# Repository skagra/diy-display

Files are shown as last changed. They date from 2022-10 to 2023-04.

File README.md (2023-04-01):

# DIY DISPLAY

A simple memory mapped *OLED display* for the [DIY CPU](https://github.com/skagra/diy-cpu-meta) project.

A `SSD1306` OLED is used to show:

* Two digital values (`value 1` and `value 2`), in binary, hex and decimal.
* A scrolling line of text.

# Interface

The display is interrupt driven.  If the `ENABLE` pin is high, then on a rising edge on the `INTERRUPT` pin the following values are captured :

* `DATA` - 8 bits of data.
* `ADDR` - 2 bits indicating whether the data value should be shown as `value 1`, `value 2` or on the scrolling text line.

`ADDR` encoding is:

| Value | Meaning |
| ----- | --- |
| 0x00  | Digital value 1 |
| 0x01  | Digital value 2 |
| 0x02  | Scrolling text  |
| 0x11  | Unused |

# Circuit

The pin out is defined in [Pins.h](Pins.h).

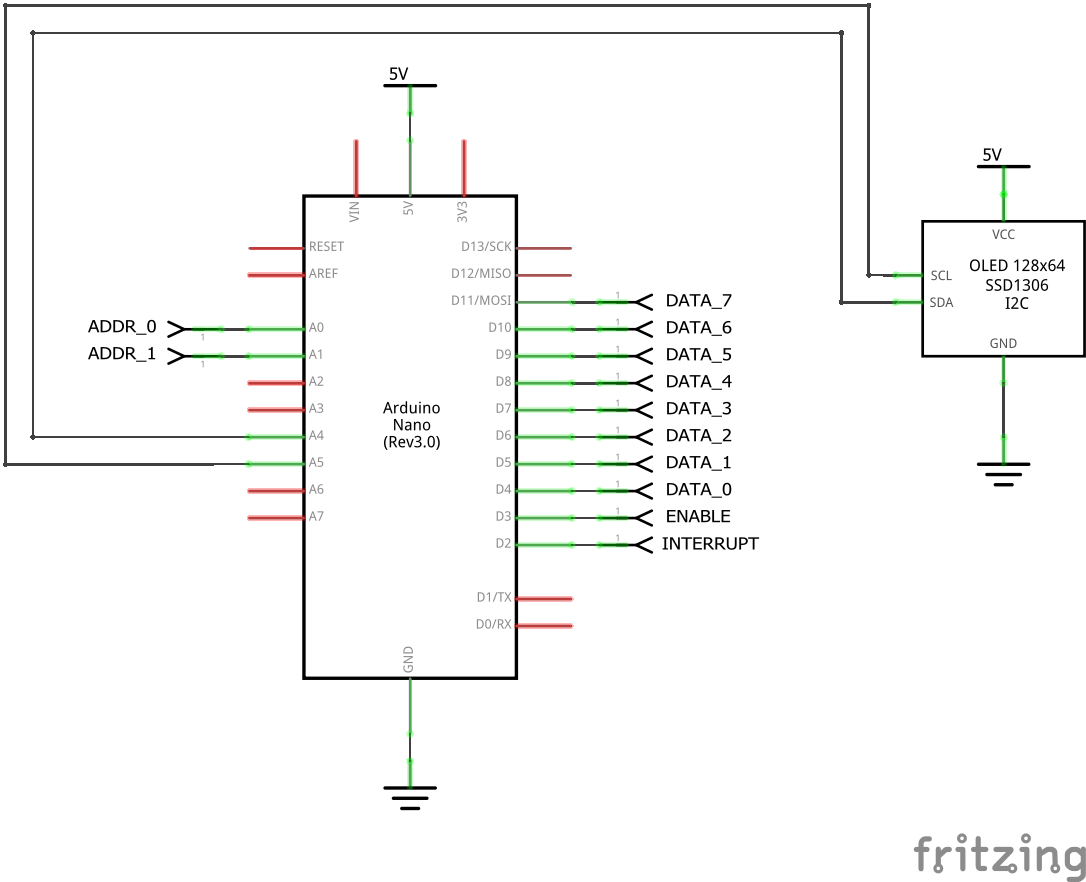
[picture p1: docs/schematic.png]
Schematic


# Testing

A separate testing project, which puts the display through its paces, may be found [here](https://github.com/skagra/diy-display-tester).

# Board

The following shows the display board together with the test rig.

Board

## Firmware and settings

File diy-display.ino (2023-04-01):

#include "Pins.h"
#include <Adafruit_SSD1306.h>
#include <splash.h>

#include <Wire.h>
#include <Adafruit_GFX.h>
#include "StatusDisplay.h"

/*
 * Operation values encoded on the address lines.
 *
 * Each value defines a particular display location/format.
 */
#define OP_VALUE_ONE 0x00 // Display on digital value 1
#define OP_VALUE_TWO 0x01 // Display on digital value 2
#define OP_MESSAGE 0x02   // Display on scrolling text line

/*
 * SSD1306 OLED Display settings
 *
 * Note: This display uses i2c and so the SDA and SCL (A4/A5 on a Nano)
 */
#define SCREEN_ADDRESS 0x3C
#define SCREEN_WIDTH 128 // OLED display width, in pixels
#define SCREEN_HEIGHT 64 // OLED display height, in pixels
#define OLED_RESET -1    // Reset pin # (or -1 if sharing Arduino reset pin)

// SSD1306 OLED display
Adafruit_SSD1306 display(SCREEN_WIDTH, SCREEN_HEIGHT, &Wire, OLED_RESET);

// Display code
StatusDisplay *statusDisplay;

void setup()
{
    Serial.begin(9600);

    pinMode(PIN_ADDR_A0, INPUT);
    pinMode(PIN_ADDR_A1, INPUT);

    pinMode(PIN_DATA_0, INPUT);
    pinMode(PIN_DATA_1, INPUT);
    pinMode(PIN_DATA_2, INPUT);
    pinMode(PIN_DATA_3, INPUT);
    pinMode(PIN_DATA_4, INPUT);
    pinMode(PIN_DATA_5, INPUT);
    pinMode(PIN_DATA_6, INPUT);
    pinMode(PIN_DATA_7, INPUT);

    pinMode(PIN_ENABLE, INPUT);
    pinMode(PIN_INTERRUPT, INPUT);

    // SSD1306_SWITCHCAPVCC = generate display voltage from 3.3V internally
    if (!display.begin(SSD1306_SWITCHCAPVCC, SCREEN_ADDRESS))
    {
        Serial.println(F("SSD1306 allocation failed"));
        for (;;)
            ;
    }

    statusDisplay = new StatusDisplay(&display);

    statusDisplay->setHexValueOne(0xFF);
    statusDisplay->setHexValueTwo(0xFF);
    statusDisplay->addMessage("DIY CPU");
    statusDisplay->display();
    delay(500);
    statusDisplay->addMessage("...READY!");
    statusDisplay->display();
    delay(500);
    statusDisplay->clearMessage();
    statusDisplay->setHexValueOne(0);
    statusDisplay->setHexValueTwo(0);
    statusDisplay->display();

    attachInterrupt(digitalPinToInterrupt(PIN_INTERRUPT), handleInterrupt, RISING);
}

// Globals to grab data/addr values
#define BUFFER_SIZE 64

byte addrBuffer[BUFFER_SIZE];
byte dataBuffer[BUFFER_SIZE];
volatile int writeBufferIndex = 0;
volatile int buffered = 0;
volatile int readBufferIndex = 0;

void handleInterrupt()
{
    if (digitalRead(PIN_ENABLE) == HIGH && buffered < BUFFER_SIZE)
    {
        // Get the address bits
        addrBuffer[writeBufferIndex] = PINC & 0x03;

        // Get the data bits
        dataBuffer[writeBufferIndex] = (PIND >> 4) | (PINB << 4);

        if (writeBufferIndex < BUFFER_SIZE - 1)
        {
            writeBufferIndex++;
        }
        else
        {
            writeBufferIndex = 0;
        }
        buffered++;
    }
}

// Character buffer to send message characters to display
char messageBuffer[2];

void loop()
{
    if (buffered > 0)
    {
        noInterrupts();
        byte localAddr = addrBuffer[readBufferIndex];
        byte localData = dataBuffer[readBufferIndex];

        if (readBufferIndex < BUFFER_SIZE - 1)
        {
            readBufferIndex++;
        }
        else
        {
            readBufferIndex = 0;
        }
        buffered--;
        interrupts();

        switch (localAddr)
        {
        case (OP_VALUE_ONE):
            statusDisplay->setHexValueOne(localData);
            break;
        case (OP_VALUE_TWO):
            statusDisplay->setHexValueTwo(localData);
            break;
        case (OP_MESSAGE):
            if (localData != 0)
            {
                messageBuffer[0] = localData;
                messageBuffer[1] = (char)0;
                statusDisplay->addMessage(messageBuffer);
            }
            else
            {
                statusDisplay->clearMessage();
            }
            break;
        default:
            Serial.println("ERROR: Invalid address");
            break;
        }
        statusDisplay->display();
    }
}

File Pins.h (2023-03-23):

#ifndef _PIN_DOT_H_
#define _PIN_DOT_H_

/*
 * DATA
 *
 * Byte to display:
 *
 * - LSB is on lowest numbered pin
 * - The byte is interpreted either as a character or a number
 *   depending on the operation selected by the ADDR pins.
 */
#define PIN_DATA_0 4  // PIN 7
#define PIN_DATA_1 5  // PIN 8
#define PIN_DATA_2 6  // PIN 9
#define PIN_DATA_3 7  // PIN 10
#define PIN_DATA_4 8  // PIN 11
#define PIN_DATA_5 9  // PIN 12
#define PIN_DATA_6 10 // PIN 13
#define PIN_DATA_7 11 // PIN 14

/*
 * ADDR
 *
 * The value selects the operation (below).
 *
 * - LSB is on lowest numbered pin
 */
#define PIN_ADDR_A0 PIN_A0 // PIN 10
#define PIN_ADDR_A1 PIN_A1 // PIN 20

/*
 * Interrupt
 *
 * Values are read from the DATA and ADDR pins on a rising edge on the interrupt line.
 */
#define PIN_INTERRUPT 2 // PIN 5

/*
 * ENABLE
 *
 * Values will only be read from DATA and ADDR when ENABLE is high.
 */
#define PIN_ENABLE 3 // PIN 6

#endif

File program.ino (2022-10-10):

#include <Adafruit_SSD1306.h>
#include <splash.h>

#include <Adafruit_SSD1306.h>
#include <Wire.h>
#include <Adafruit_GFX.h>
#include "StatusDisplay.h"

#define PIN_DATA_0 4  // PIN 7
#define PIN_DATA_1 5  // PIN 8
#define PIN_DATA_2 6  // PIN 9
#define PIN_DATA_3 7  // PIN 10
#define PIN_DATA_4 8  // PIN 11
#define PIN_DATA_5 9  // PIN 12
#define PIN_DATA_6 10 // PIN 13
#define PIN_DATA_7 11 // PIN 14

#define PIN_ADDR_A0 PIN_A0 // PIN 10
#define PIN_ADDR_A1 PIN_A1 // PIN 20
#define PIN_ADDR_A2 PIN_A2 // PIN 21
#define PIN_ADDR_A3 PIN_A3 // PIN 22

#define PIN_ENABLE 3 // PIN 6
#define PIN_CLOCK 2  // PIN 5

#define SCREEN_ADDRESS 0x3C
#define SCREEN_WIDTH 128 // OLED display width, in pixels
#define SCREEN_HEIGHT 64 // OLED display height, in pixels
#define OLED_RESET -1    // Reset pin # (or -1 if sharing Arduino reset pin)

// SDA 23 A4
// SCL 24 A5

#define OP_VALUE_ONE 0x00
#define OP_VALUE_TWO 0x01
#define OP_MESSAGE 0x02

Adafruit_SSD1306 display(SCREEN_WIDTH, SCREEN_HEIGHT, &Wire, OLED_RESET);
StatusDisplay *statusDisplay;

void setup()
{
    Serial.begin(9600);

    // SSD1306_SWITCHCAPVCC = generate display voltage from 3.3V internally
    if (!display.begin(SSD1306_SWITCHCAPVCC, SCREEN_ADDRESS))
    {
        Serial.println(F("SSD1306 allocation failed"));
        for (;;)
            ;
    }

    statusDisplay = new StatusDisplay(&display);

    attachInterrupt(digitalPinToInterrupt(PIN_CLOCK), handleClock, RISING);
}

volatile byte addr;
volatile byte data;
volatile bool dataExists = false;

void handleClock()
{
    if (digitalRead(PIN_ENABLE) == HIGH)
    {
        // Get the address bits
        addr = (digitalRead(PIN_ADDR_A0) == HIGH) |
               (digitalRead(PIN_ADDR_A1) == HIGH) << 1 |
               (digitalRead(PIN_ADDR_A2) == HIGH) << 2 |
               (digitalRead(PIN_ADDR_A3) == HIGH) << 3;

        // Get the data bits
        data = (digitalRead(PIN_DATA_0) == HIGH) |
               (digitalRead(PIN_DATA_1) == HIGH) << 1 |
               (digitalRead(PIN_DATA_2) == HIGH) << 2 |
               (digitalRead(PIN_DATA_3) == HIGH) << 3 |
               (digitalRead(PIN_DATA_4) == HIGH) << 4 |
               (digitalRead(PIN_DATA_5) == HIGH) << 5 |
               (digitalRead(PIN_DATA_6) == HIGH) << 6 |
               (digitalRead(PIN_DATA_7) == HIGH) << 7;

        dataExists = true;
    }
}

char buffer[2];

void loop()
{
    if (dataExists)
    {
        dataExists = false;
        switch (data)
        {
        case (OP_VALUE_ONE):
            statusDisplay->setHexValueOne(data);
            break;
        case (OP_VALUE_TWO):
            statusDisplay->setHexValueTwo(data);
            break;
        case (OP_MESSAGE):
            buffer[0] = data;
            buffer[1] = (char)0;
            statusDisplay->addMessage(buffer);
            break;
        default:
            Serial.println("ERROR: Invalid address");
            break;
        }
    }
}

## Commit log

2022-10-09 Removed cpp props
2022-10-14 Removed arduino.json
2022-10-14 Added arduino.json to .gitignore
2023-03-24 Added schematic
    [schematic.fzz]
2023-03-26 Added photo of board
2023-03-28 Switching to check hardware
2023-03-28 Moved to circular buffer to avoid copying buffer
    [diy-display.ino]
